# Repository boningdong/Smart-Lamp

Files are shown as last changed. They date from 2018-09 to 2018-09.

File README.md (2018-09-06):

# Wireless-Charging-Smart-Lamp-Project
This project is a Wireless Charging Smart Lamp.

## Purpose
This lamp is actually a gift I built for my friends and teachers before I came to US in 2016.
I was in charge of the hardware, embedded software and industrial design respectively. So this is also a good practice project for me to design a product totally by myself from hardware layer to software layer.

## Features
- Light: The lamp supports 65k color space. Users can change color with their smartphone.
- Multiple Charging Mode: The lamp supports wireless charing and cable charging. You can choose either way you want.
- Capacitive Touch Control: User can turn on/off the lamp by touch the capacitive sensing area, and dim the light by keep touching the area for long time.
- Wireless Control: Users can control the color of the light by writing a command to the lamp through BLE.
- Battery Management: The lamp has a built-in Lithium Ion battery inside. When charging, the battery management circuit will control & alter the charging phase accordingly. The lamp will indicate fully charged state and low battery state to the user. User can stop the indication by simply touch the lamp.

## Development
- Hardware: Both the schematic and PCB is designed with Altium Designer. To pursue a modular design, I prototyped a BQ51013B wireless charging module and used it on my project.
- Firmware: I use MSP430 as the controller in this project becasue of its low power consumption and cheap price. So the firmware is programmed with Code Composer Studio provided by Ti.
- Design: I used Rhino to design the case and exported to STL format for 3D printing.

## Usage
- Hardware: Use altium to open the PrjPcb file to see the whole project. After open the project, you need to import the Design Used Library. Bedside Lamp V3.0.pdf includes the schematic and the screenshot of the PCB design.
- Firmware: The firmware project is located under Firmware/ folder.
- Case: To print the case, you need to open the 3dm file under 3D Models/ folder and export everything into STL.

## Photos
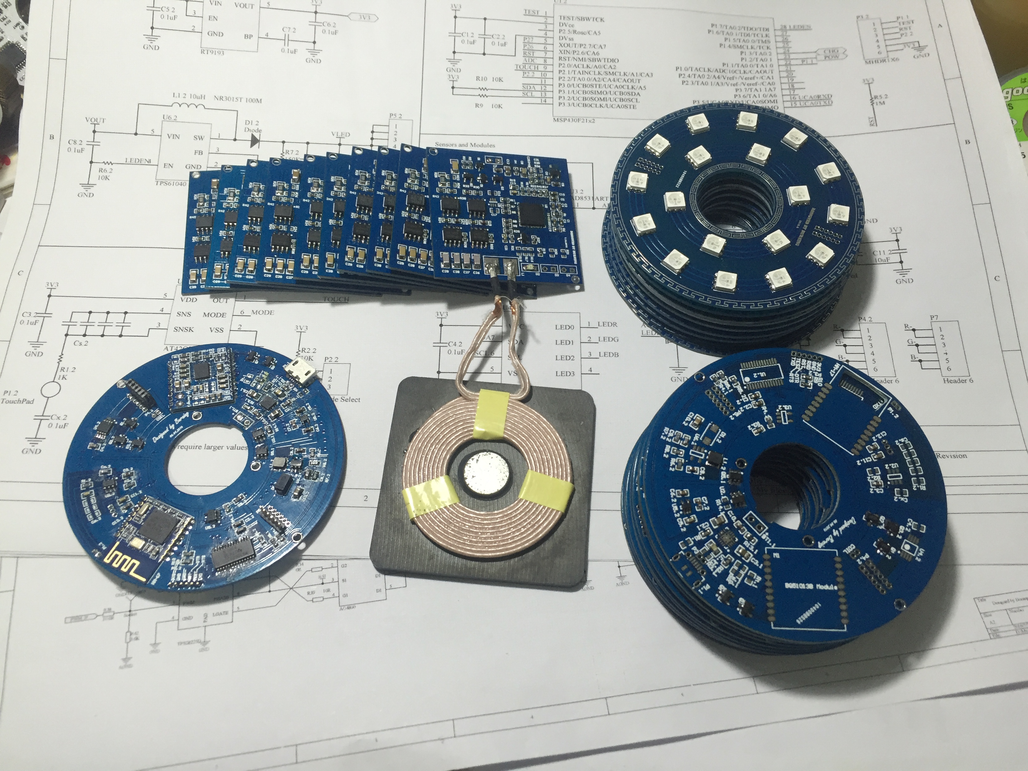
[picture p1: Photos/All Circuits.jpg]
Circuits Photos

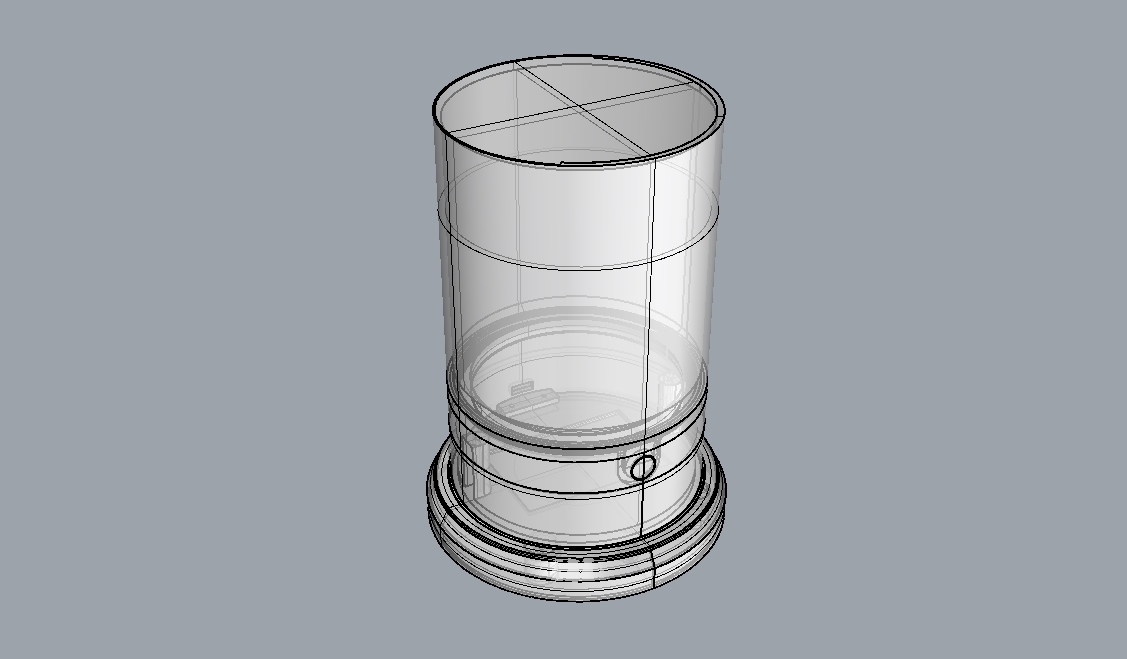
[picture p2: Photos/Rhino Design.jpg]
Rhino Deisng

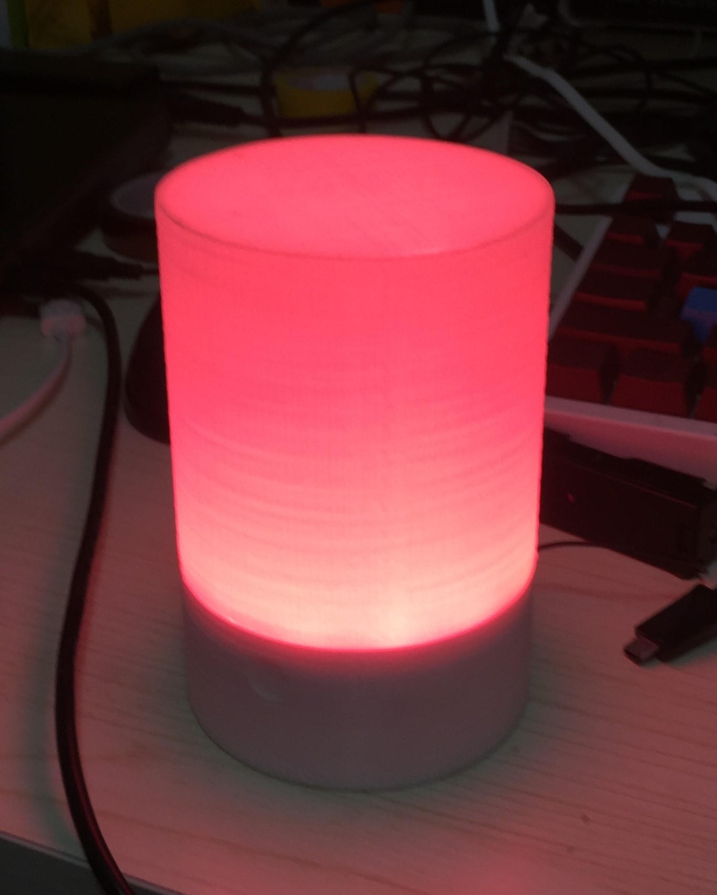
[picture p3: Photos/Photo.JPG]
Real Photo


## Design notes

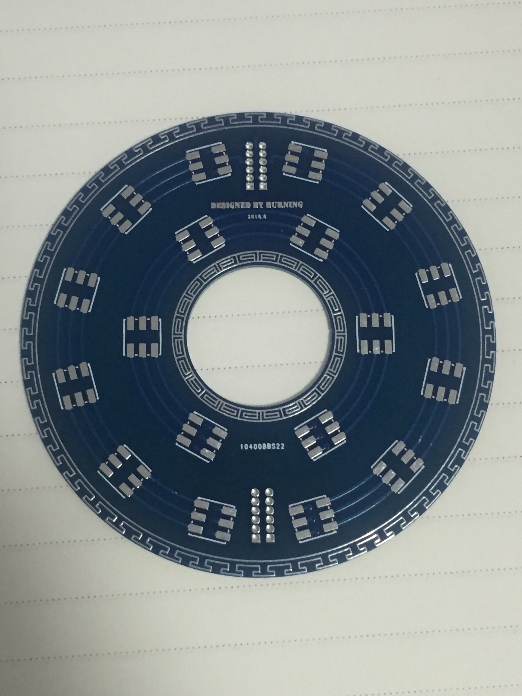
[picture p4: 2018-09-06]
Photos/LED Board.jpg

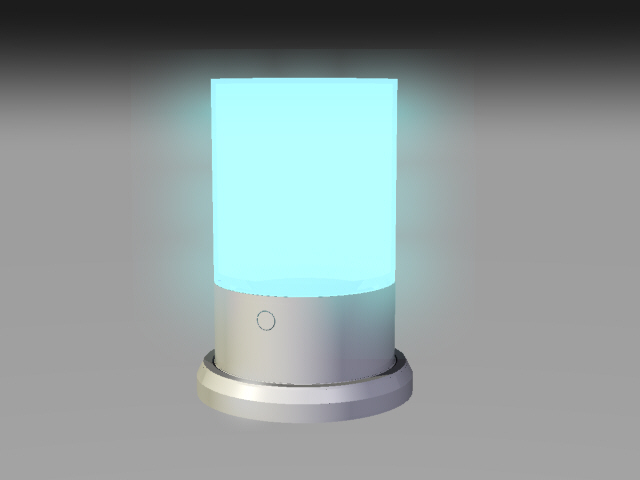
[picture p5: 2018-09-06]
Photos/Rhino Render.jpg

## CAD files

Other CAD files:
3D Models/Bedside Lamp.3dm

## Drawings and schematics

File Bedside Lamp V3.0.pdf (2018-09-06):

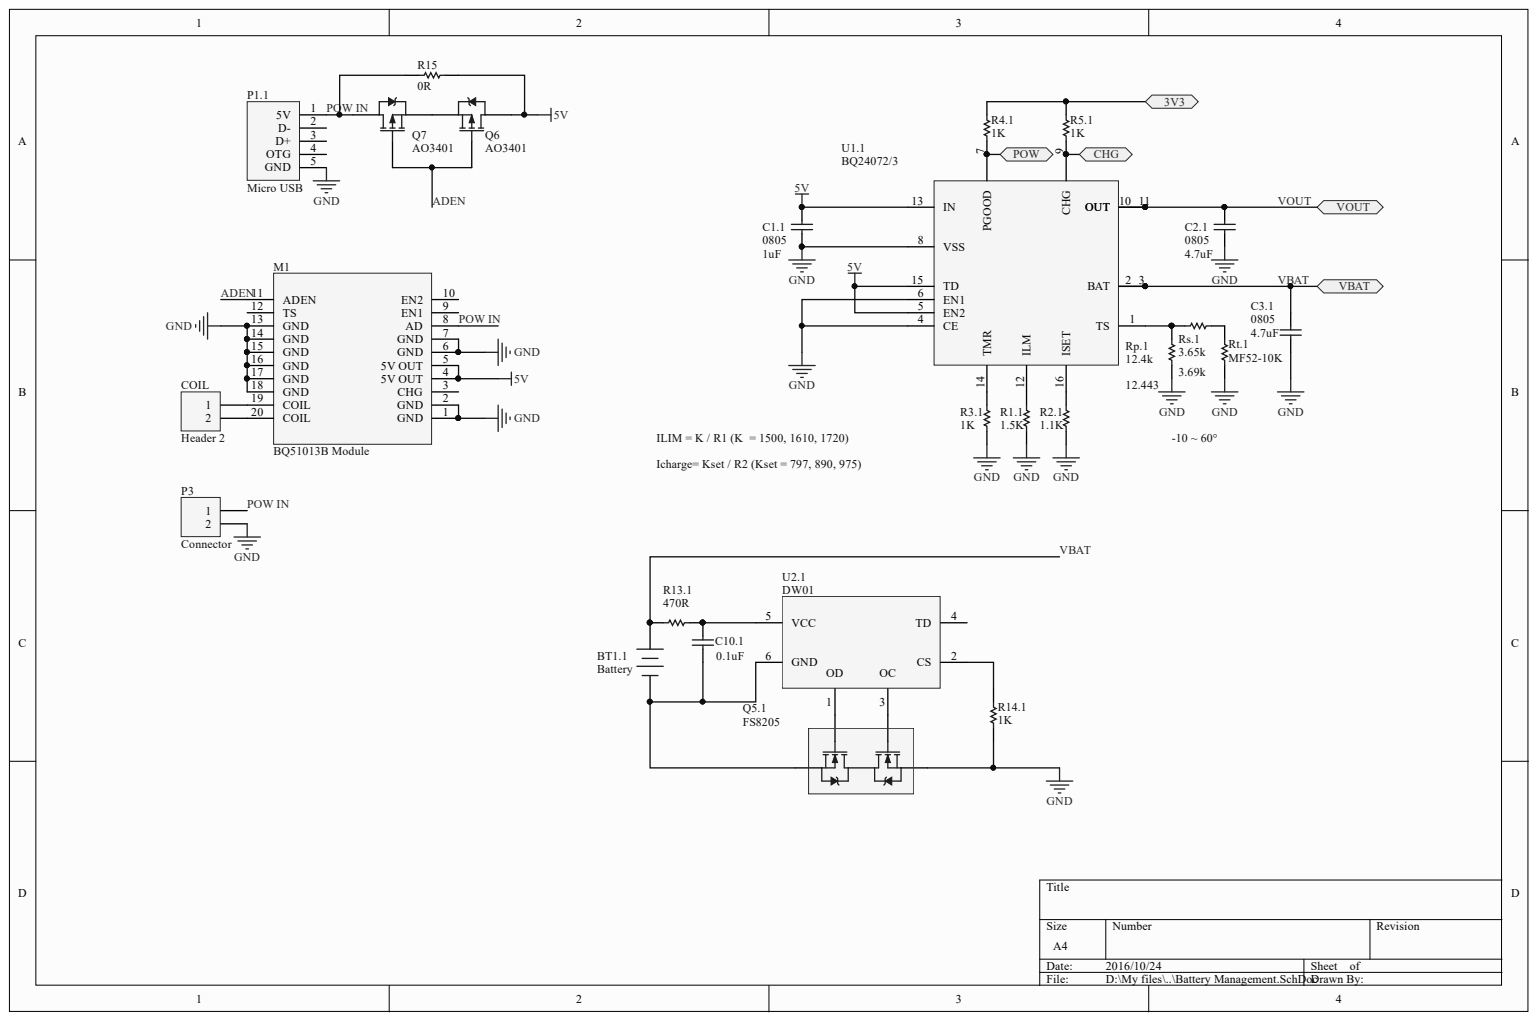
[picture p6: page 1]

GND 6

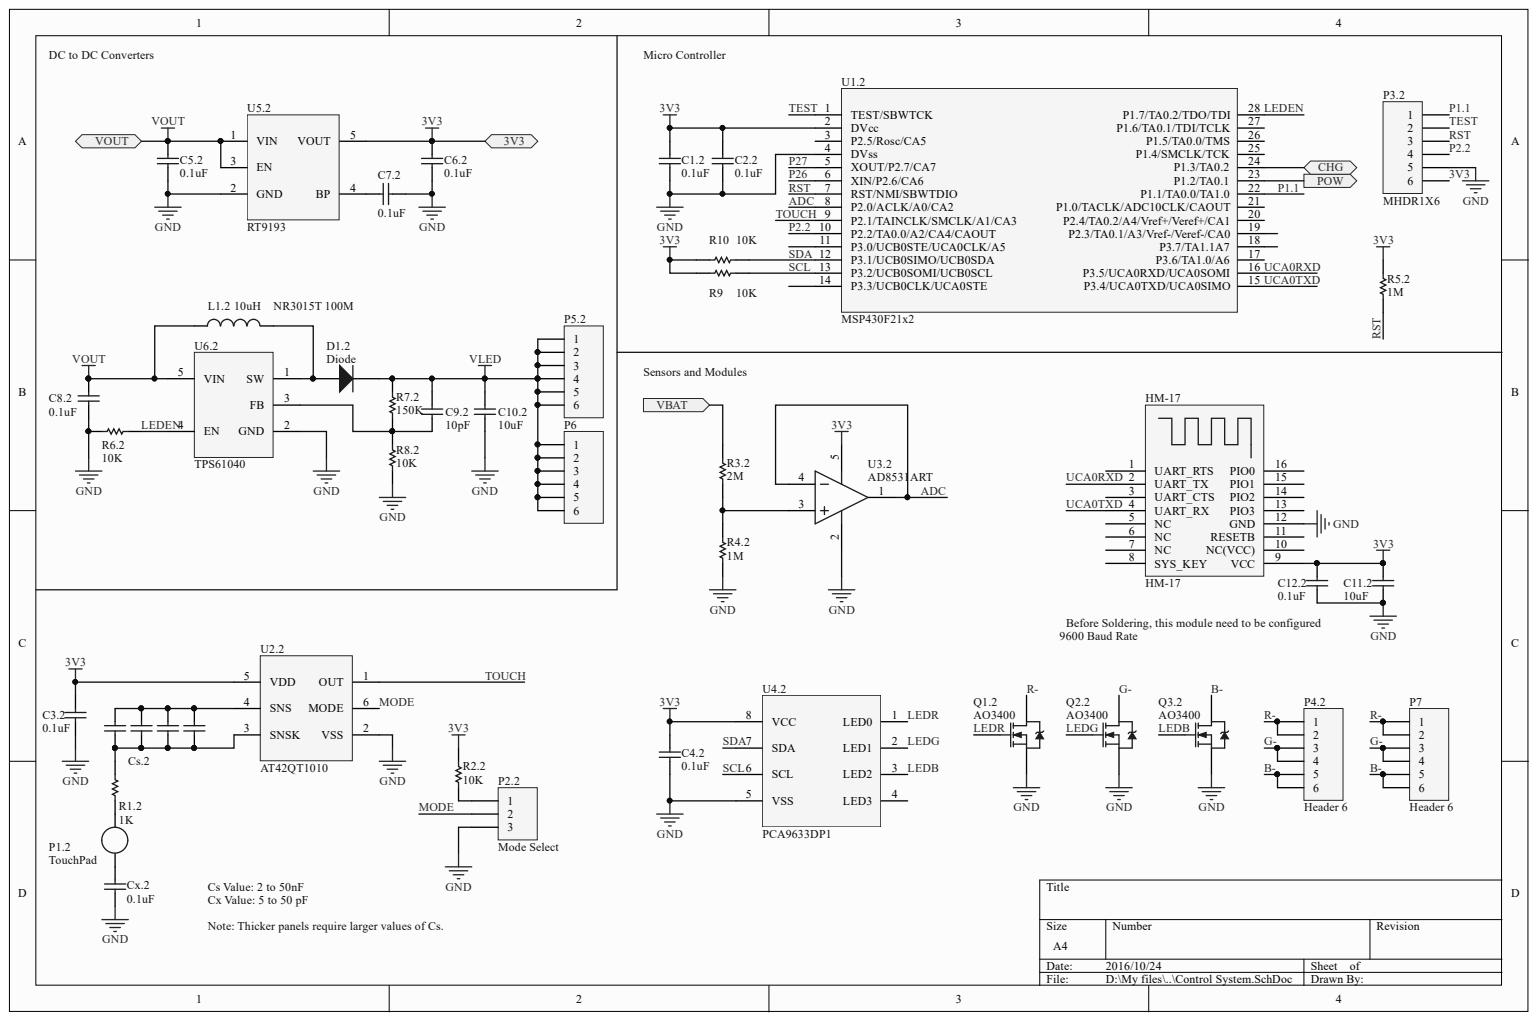
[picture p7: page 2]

DC to DC Converters

DVss 4 P2.5/Rosc/CA5 3

C2.2 P27 0.1uF P26 RST | XOUT/P2.7/CA7 5 XIN/P2.6/CA6 6 RST/NMI/SBWTDIO 7

Before Soldering, this module need to be configured
9600 Baud Rate

Cs Value: 2 to 50nF
Cx Value: 5 to 50 pF

Note: Thicker panels require larger values of Cs.

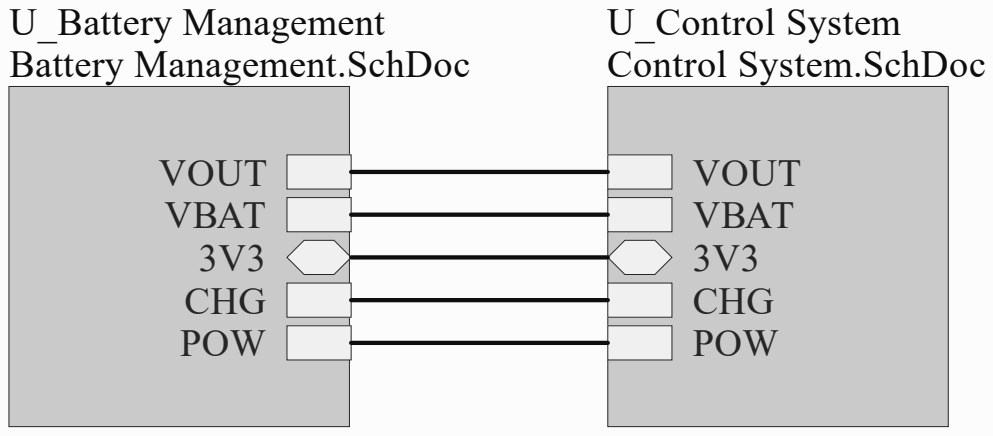
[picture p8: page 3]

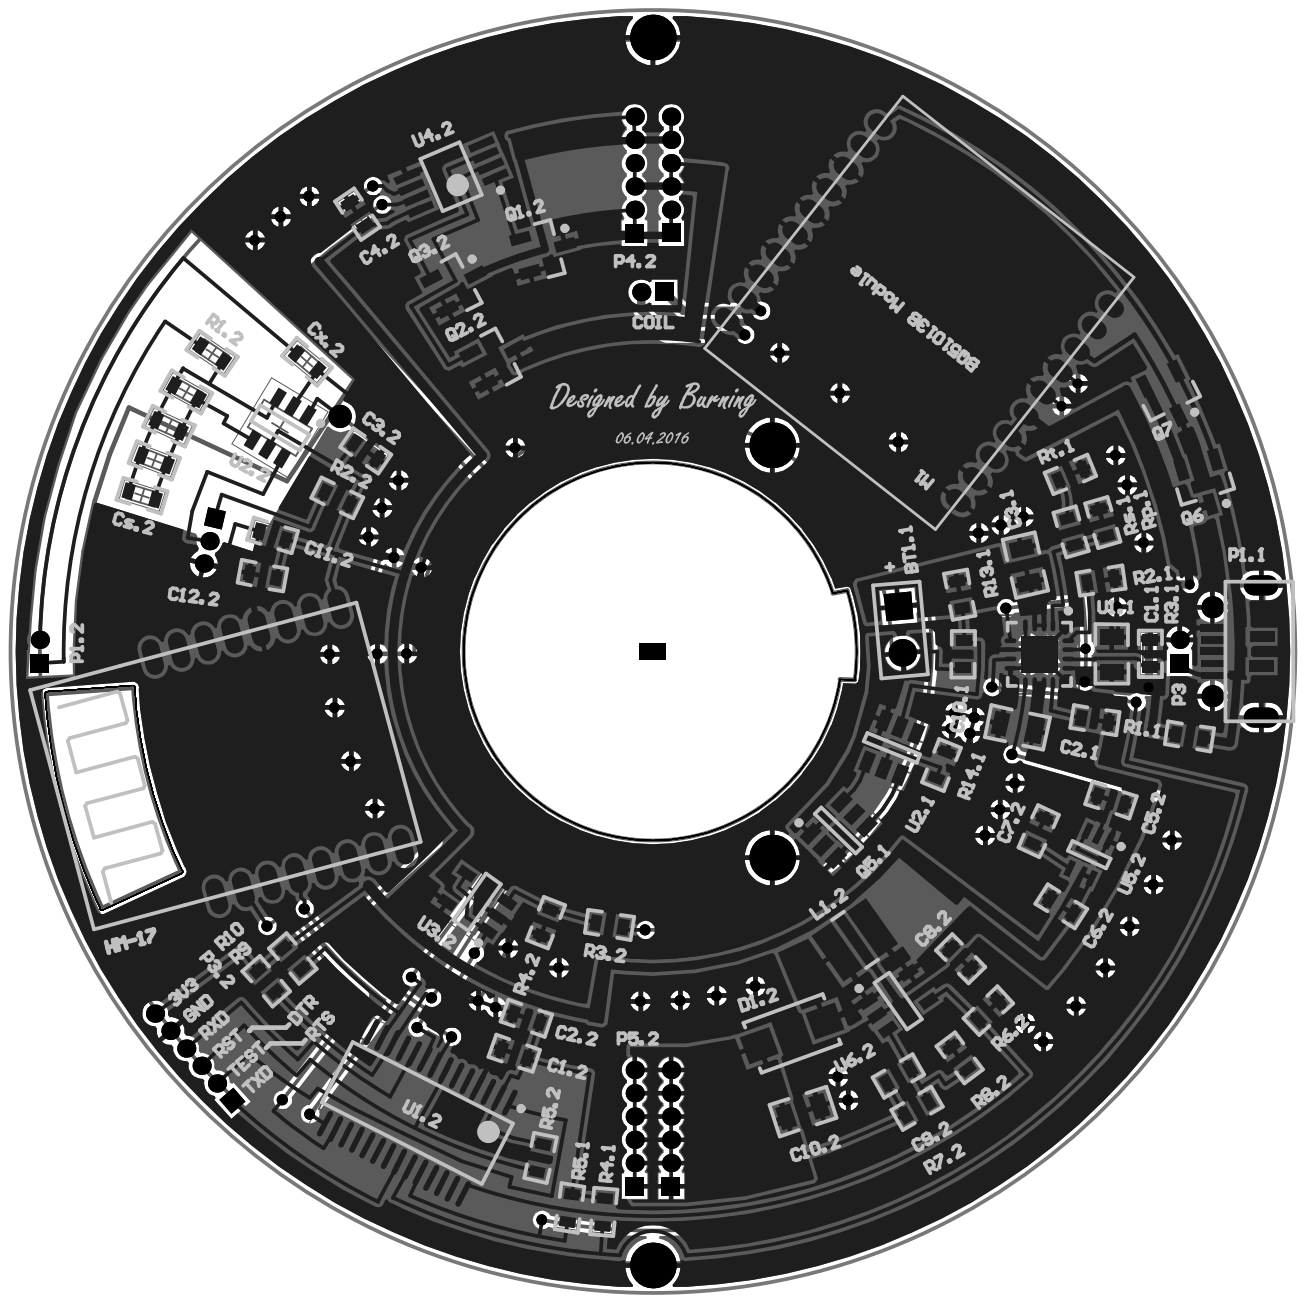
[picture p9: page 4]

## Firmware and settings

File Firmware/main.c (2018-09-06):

#include <msp430.h> 
#include <I2C.h>
#include <SysClock.h>
#include <RGB.h>
#include <UART.h>
#include <ADC.h>
#include <Timer.h>
#include <stdio.h>
#include <IO.h>
#include <GeneralFunctions.h>


/*
 * main.c
 */
void TouchPad_Init();


int main(void)
{
    WDTCTL = WDTPW | WDTHOLD;	// Stop watchdog timer
    //IO_Init();
    _EINT();
    //Clock
    Clock_init();
    SMCLK_Detectable();

    UART_init();
    I2C_init ();
    TouchPad_Init();
    ADC_Init();
    Charging_Detection_Init();
    Timer_Init();

    RGB_PowEnable();
    RGB_reset ();
    RGB_init ();

    SetColor (255, 255, 70, 255);   // Set default color to warm color and maximum brightness
    _BIS_SR(LPM0_bits + GIE);   // Enter low power Mode and enable global interrupt
}

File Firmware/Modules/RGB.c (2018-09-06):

/*
 * RGB.c
 *
 *  Created on: 2016Äê4ÔÂ30ÈÕ
 *      Author: DBN
 */

#include <msp430.h>
#include <I2C.h>
#include <RGB.h>
#include <IO.h>
#include <GeneralFunctions.h>


/*Configurated by User
 *  according to hardware design*/
#define LED_R PWM1
#define LED_G PWM2
#define LED_B PWM0

Color OldColor;
Color ColorRemember;
flashing Is_Flashing = is_not_Flashing;

//RGB Initialize and RGB Power Control
void RGB_init()
{
	SendData(MODE1,0x81);
	//SendData(MODE2,0x09);
	SendData(MODE2,0x1D);
	SendData(LEDOUT,0x3F);
	OldColor.red = 0;
	OldColor.blue = 0;
	OldColor.green = 0;
	OldColor.brightness = 0;
}

void RGB_PowEnable()
{
	P1DIR |= BIT7;
	P1OUT |= BIT7;
}

void RGB_PowDisable()
{
	P1OUT &= ~BIT7;
}


// Used for setting color
void SetColor(
		unsigned char red,
		unsigned char green,
		unsigned char blue,
		unsigned char brightness )
{
	if(	(OldColor.red == 0) 	&&
		(OldColor.green == 0) 	&&
		(OldColor.blue == 0)	&&
		(OldColor.brightness == 0))
	{
		OldColor.red = red;
		OldColor.green = green;
		OldColor.blue = blue;
		OldColor.brightness = brightness;

	}

	else
	{
		while( 	(red!=OldColor.red)		||
				(blue!=OldColor.blue)	||
				(green!=OldColor.green)	||
				(brightness!=OldColor.brightness))
		{
			OldColor.red = GetClose(red, OldColor.red);
			OldColor.green = GetClose(green, OldColor.green);
			OldColor.blue = GetClose(blue, OldColor.blue);
			OldColor.brightness = GetClose(brightness, OldColor.brightness);

			SendData(LED_R,OldColor.red);
			SendData(LED_G,OldColor.green);
			SendData(LED_B,OldColor.blue);
			SendData(GRPPWM,OldColor.brightness);
		}
	}
	SendData(LED_R,red);
	SendData(LED_G,green);
	SendData(LED_B,blue);
	SendData(GRPPWM,brightness);
}

void RGB_reset()
{
	UCB0I2CSA = 0x03;
	SendData(0xA5,0x5A);
	UCB0I2CSA = 0x62;
}

void RestoreColor()
{
	SetColor(ColorRemember.red, ColorRemember.green, ColorRemember.blue, ColorRemember.brightness);
}

void RememberColor()
{
	ColorRemember.red = GetRed();
	ColorRemember.green = GetGreen();
	ColorRemember.blue = GetBlue();
	ColorRemember.brightness = GetBright();
}


void Low_Battery_Power_Flash()
{
	int Flash_Times;
	RememberColor();
	for(Flash_Times = 2; Flash_Times > 0; Flash_Times --)
	{
		SetColor(255,130,130,200);
		delay(200);
		RestoreColor();
		delay(200);
	}
}

void High_Battery_Power_Flash()
{
	int Flash_Times;
	RememberColor();
	for(Flash_Times = 2; Flash_Times > 0; Flash_Times --)
	{
		SetColor(140,255,160,200);
		delay(200);
		RestoreColor();
		delay(200);
	}
}

void Power_Plug_In_Flash()
{
	int Flash_Times;
	RememberColor();
	delay(50);
	if(Check_Power_Status())
	{
		unsigned char P1_Status = P1OUT;
		if(!(P1_Status & BIT7))
		{
			RememberColor();
			SetColor(255,255,255,0);
			delay(20);
		}
		RGB_PowEnable();
		for(Flash_Times = 2; Flash_Times > 0; Flash_Times --)
		{
			SetColor(100,210,240,200);
			delay(200);
			if(!(P1_Status & BIT7))
			{
				SetColor(255,255,255,0);
			}
			else
			{
				RestoreColor();
			}
			delay(200);
		}
		if(!(P1_Status & BIT7))
		{
			RGB_PowDisable();
			delay(200);
			RestoreColor();
		}
	}
}

void Acknowledge_Flash()
{
	delay(20);
	RememberColor();
	SetColor(200,0,255,200);
	RestoreColor();
	delay(20);
}

//Conditions
unsigned char GetRed()
{
	return OldColor.red;
}

unsigned char GetGreen()
{
	return OldColor.green;
}

unsigned char GetBlue()
{
	return OldColor.blue;
}

unsigned char GetBright()
{
	return OldColor.brightness;
}

// Used for changing the color smoothly but not abruptly
unsigned char GetClose (unsigned char target, unsigned char old)
{
	if(old < target)
	{
		old++;
		return old;
	}

	else if(old > target)
	{
		old--;
		return old;
	}

	else
	{
		return old;
	}
}
